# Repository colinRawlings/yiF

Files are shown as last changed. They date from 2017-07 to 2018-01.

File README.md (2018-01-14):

# The yiF
*a foolish combination of action cameras and SLR lenses*

## introduction 

This is a project seeking to replace an action cameras fisheye lens with one of the low cost plastic bodied EFs STM zoom lenses from Canon.  Ideally this combines the action camera's high frame rates (HD at 240 frames/second) with the lens' zoom, depth of field control and active image stabilisation.  Some example footage is here:

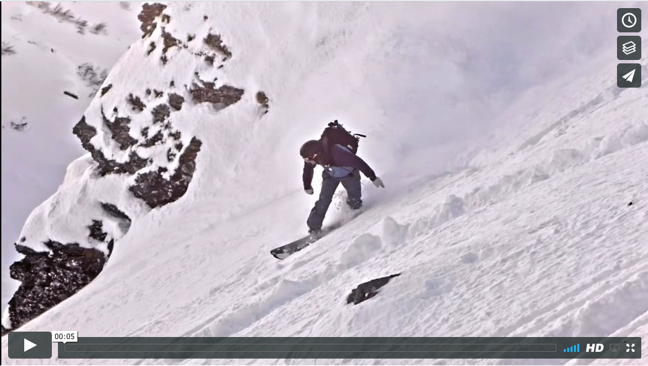
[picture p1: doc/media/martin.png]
example footage (https://vimeo.com/224622844)


The lens is controlled via an Arduino micro and a Yi 4k+ was used for the action camera.  Via the arduino the lens' focus, aperture and image stabilisation motors can be controlled.  The housing is 3D printed and a commlite EF-EOSM adaptor is used for mounting the lens.

For video monitoring the Yi's in-built display combined with an optical viewfinder (the kinotehnik LCDVF 3/2) or an external monitor (smartphone or the ikan VL35) was used.  

The system was tested with several of the EFs STM lenses (10-18 mm, 18-135 mm f3.5 and 55-250 mm f4) and a sigma 35 mm f1.4. The system exhibits a roughly 3x crop sensor, this amplifies the available travel of the image stabiliser, increases the reach of the lens and improves the depth of field control.  

So far nothing bad has happened to the lenses however: 

**You can apparently burn the aperture motor in Canon lenses quite easily.**

*I take no responsibility for any damage caused by the things in this repo.*

The starting point for this work was this article:

https://pickandplace.wordpress.com/2011/10/05/canon-ef-s-protocol-and-electronic-follow-focus/

from here I used a Saleae logic analyser to record the conversations between the lenses and a 650D.  These were then analysed in Matlab since in particular I needed the command to start the image stabilisation motor and activate the manual focus ring (the STM lenses are “focus by wire”).

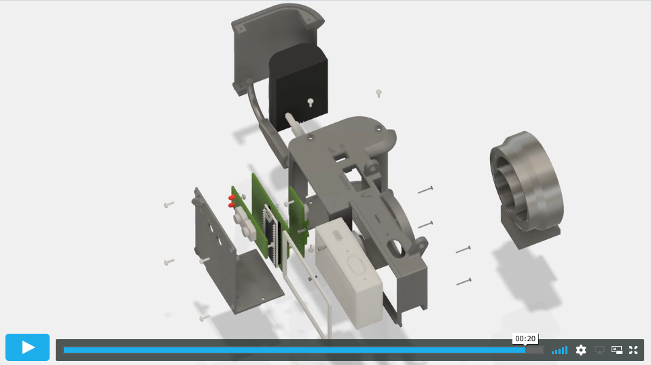
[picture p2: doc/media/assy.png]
assembly (https://vimeo.com/248812464)


## code

This comes in several parts

* A python class for communicating over usb (/serial port) with the arduino.
* [The arduino code](https://github.com/colinRawlings/yiFu)
* The matlab (/octave?) code for parsing the csv files generated by the logic analyser

## cad

The cad was done in Fusion (free for the first year).  The assembly is here: http://a360.co/2sxdWEE

the stl files for printing are in cad/fab.  They are only suitable for selective laser sintering or HP jet fusion of nylon.  I used [3Dhubs.com](https://www.3dhubs.com) to find a nearby printer.

## electronics

The electronics design was done in kicad.  Note the arduino can control the power to the lens.  The entire lens is switch off after each movement of the aperture motor rather than relying on the motor off command being successfully received.  The gerber files are in elec/fab.  I eventually settled on powering the system with an LP-E6 camera battery.

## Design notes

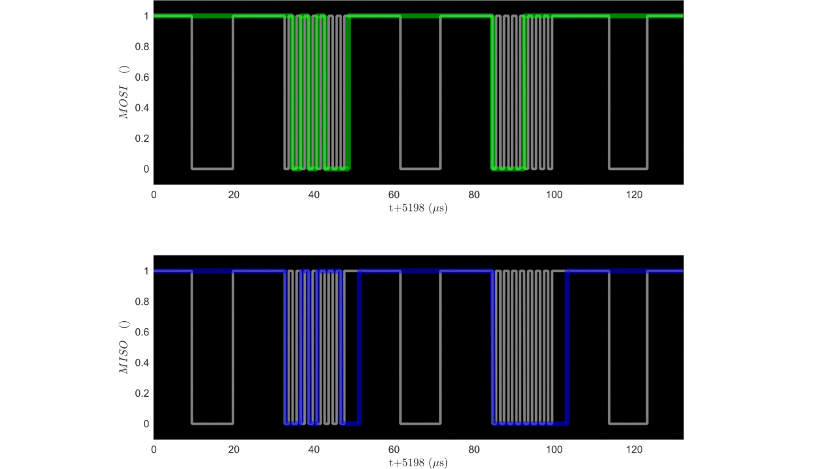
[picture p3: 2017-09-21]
doc/media/anim.gif

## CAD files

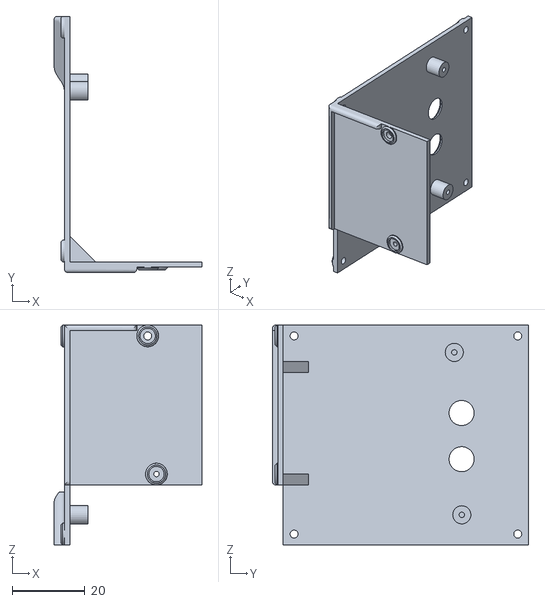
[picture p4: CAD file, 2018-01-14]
cad/fab/case_back.stl
40.6 x 70.5 x 60.5

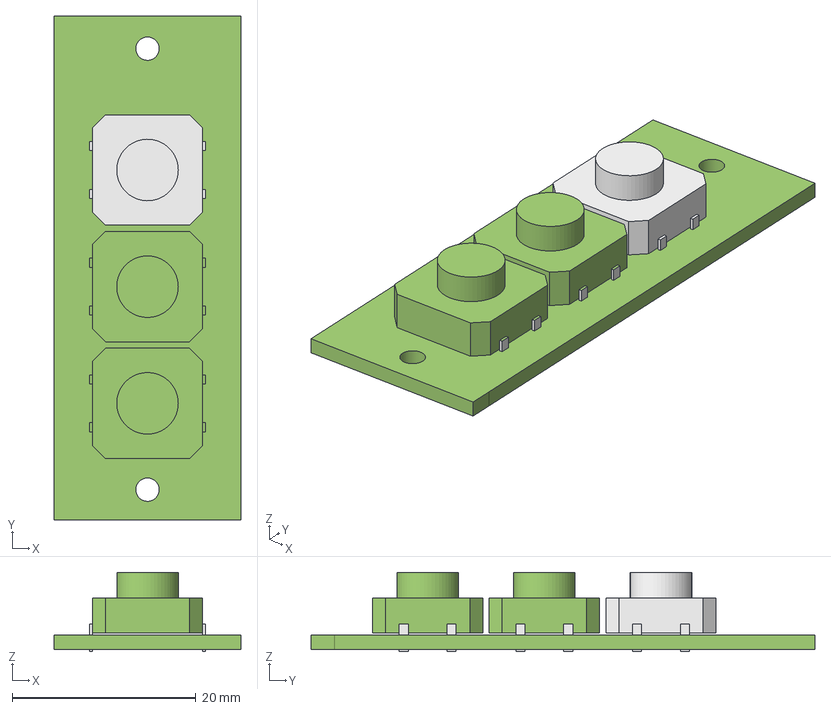
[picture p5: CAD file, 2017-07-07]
pcb/ard_shield/cad/brd2.step
20.3 x 54.9 x 8.60 mm

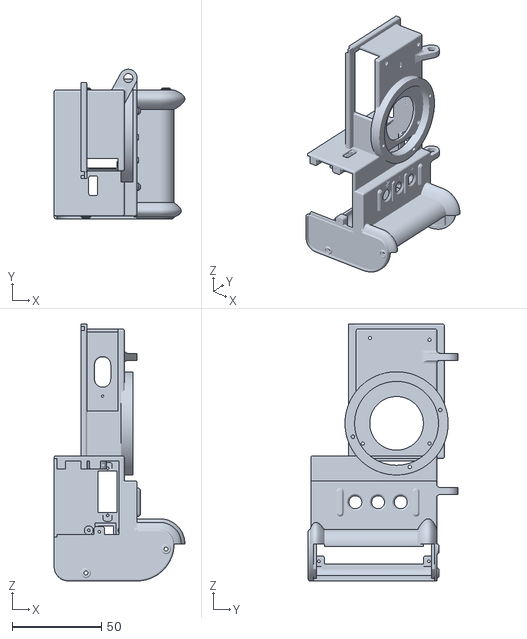
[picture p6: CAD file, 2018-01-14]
cad/fab/housing.stl
73.1 x 83.6 x 143.7

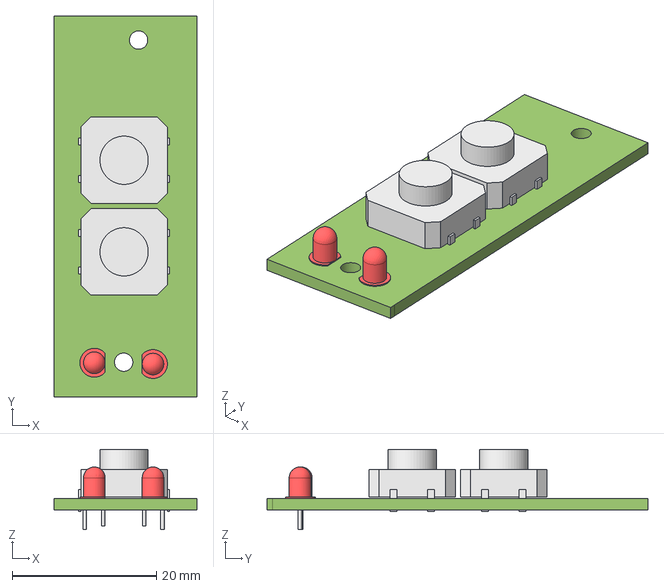
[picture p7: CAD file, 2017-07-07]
pcb/ard_shield/cad/brd3.step
19.8 x 52.8 x 11.1 mm

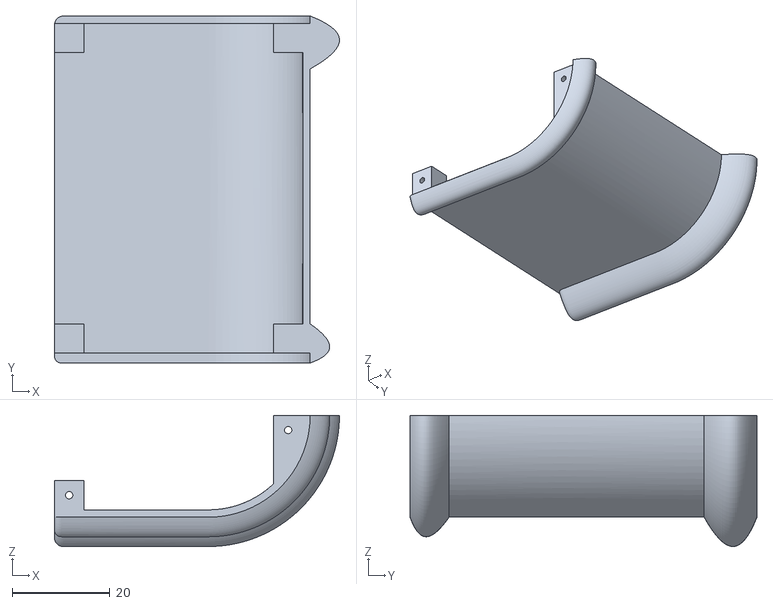
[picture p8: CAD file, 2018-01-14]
cad/fab/battery_hatch.stl
58.3 x 71.0 x 26.8

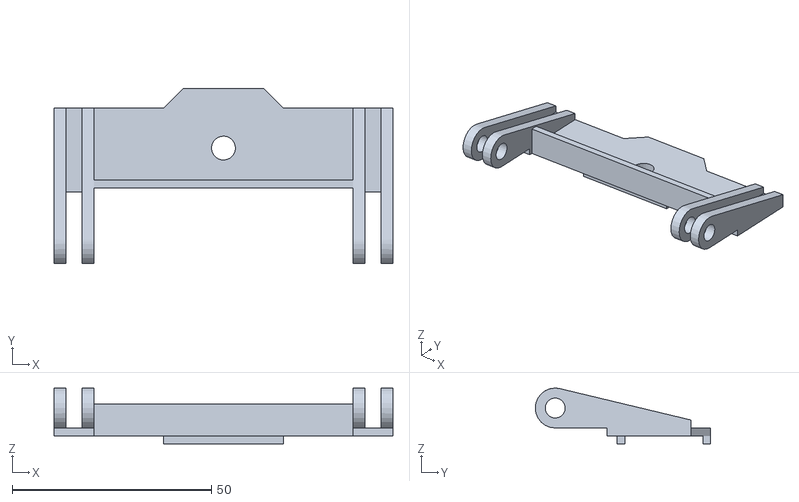
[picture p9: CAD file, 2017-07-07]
cad/fab/screen_mnt.stl
85.0 x 44.0 x 14.0

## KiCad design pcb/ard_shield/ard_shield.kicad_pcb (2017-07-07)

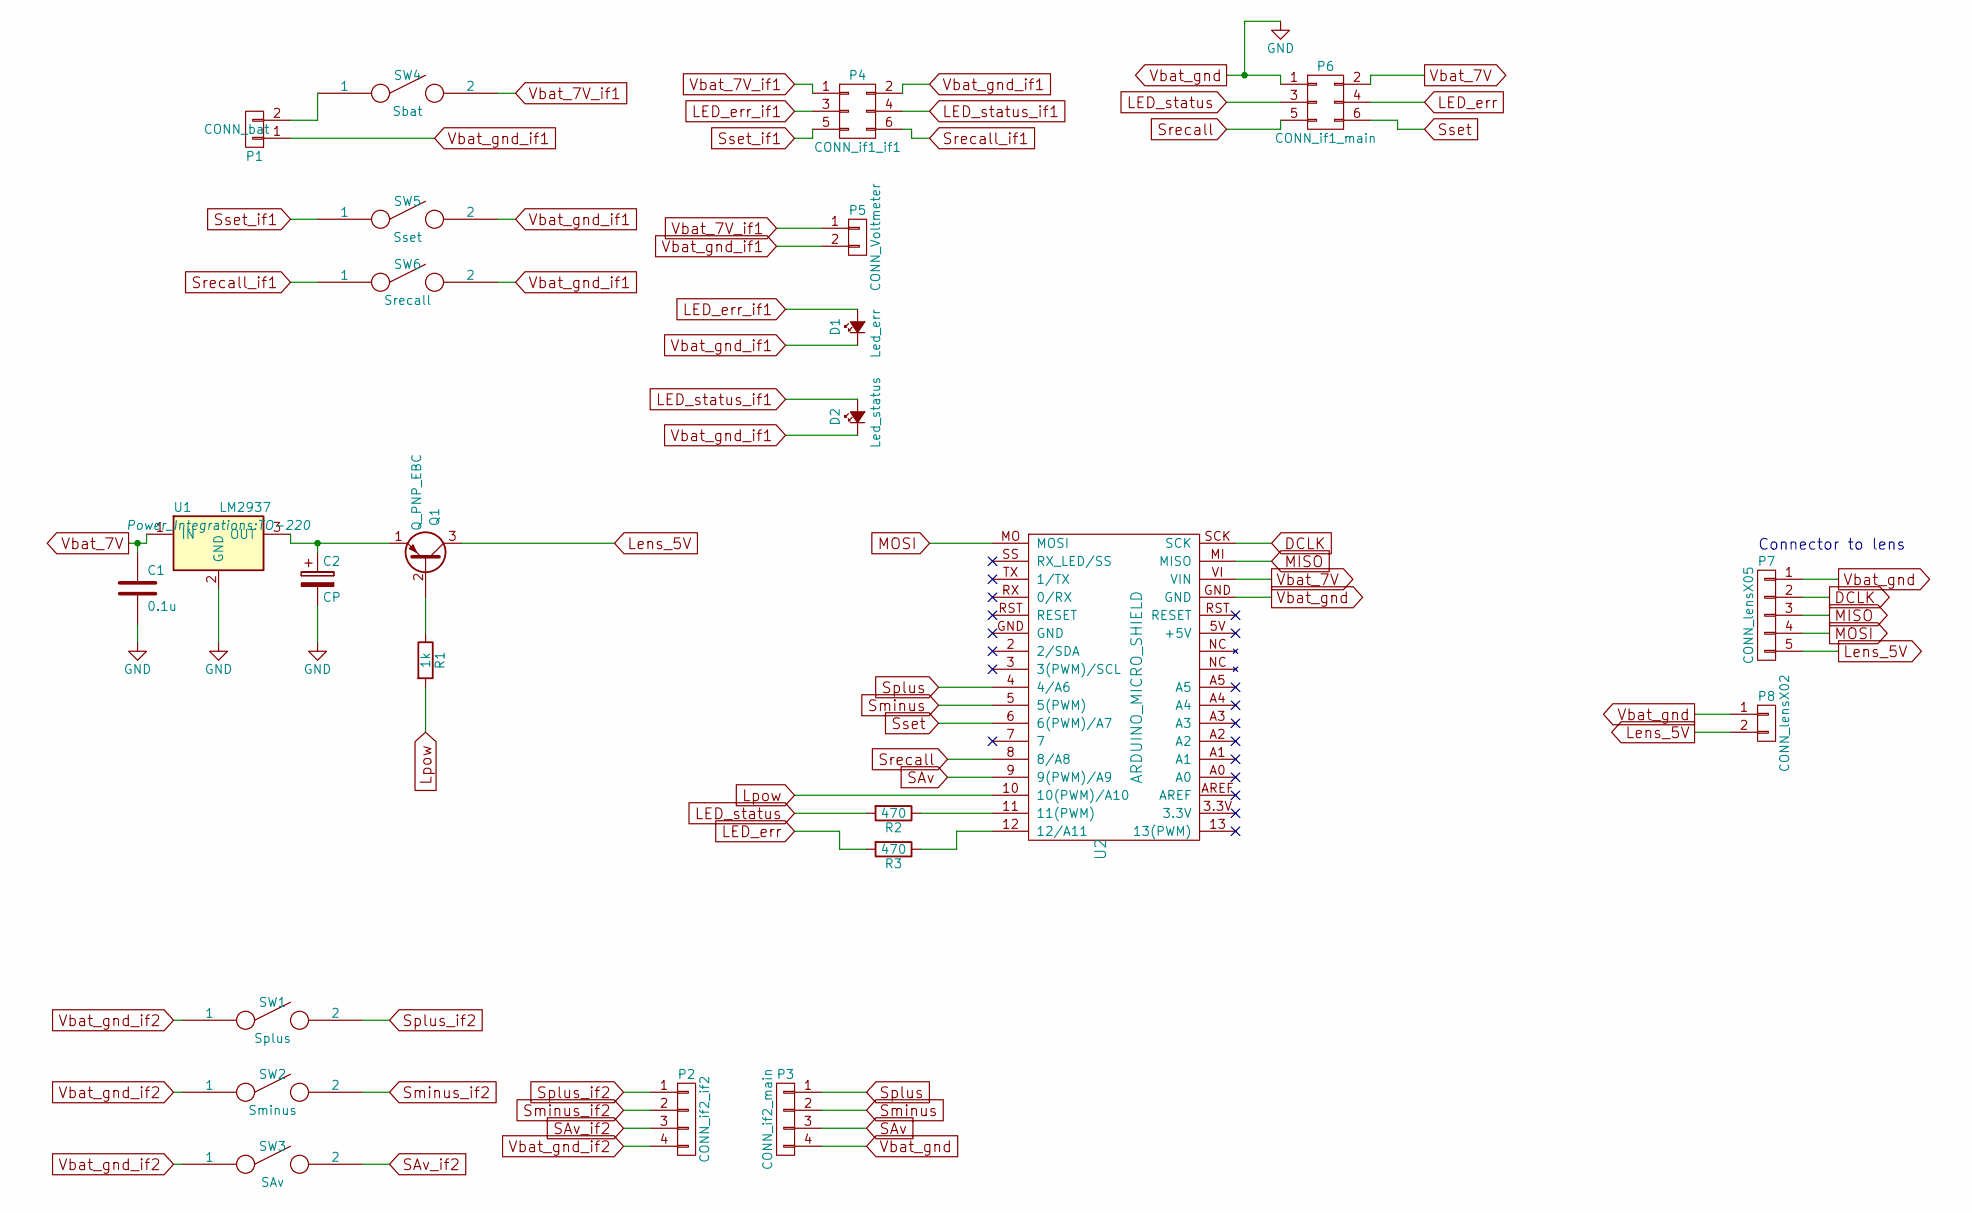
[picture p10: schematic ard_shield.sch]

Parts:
C1: 0.1u; C_Disc_D3_P2.5
C2: CP; C_Rect_L7_W2_P5
D1: Led_err; LED-3MM
D2: Led_status; LED-3MM
P1: CONN_bat; Pin_Header_Angled_1x02
P2: CONN_if2_if2; Pin_Header_Angled_1x04
P3: CONN_if2_main; Socket_Strip_Angled_1x04
P4: CONN_if1_if1; Socket_Strip_Straight_2x03
P5: CONN_Voltmeter; Pin_Header_Straight_1x02
P6: CONN_if1_main; Pin_Header_Straight_2x03
P7: CONN_lensX05; Socket_Strip_Angled_1x05
P8: CONN_lensX02; Socket_Strip_Angled_1x02
Q1: Q_PNP_EBC
R1: 1k; Resistor_Horizontal_RM7mm
R2, R3: 470; Resistor_Horizontal_RM7mm
SW1: Splus; SW_PUSH-12mm
SW2: Sminus; SW_PUSH-12mm
SW3: SAv; SW_PUSH-12mm
SW4: Sbat; SW_Matias_Quiet
SW5: Sset; SW_PUSH-12mm
SW6: Srecall; SW_PUSH-12mm
U1: LM2937; TO-220
U2: ARDUINO_MICRO_SHIELD

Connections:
DCLK: P7.2, U2.SCK
LED_err: P6.4, R3.2
LED_err_if1: D1.2 (A), P4.3
LED_status: P6.3, R2.2
LED_status_if1: D2.2 (A), P4.4
Lens_5V: P7.5, P8.2, Q1.3 (C)
Lpow: R1.2, U2.10 (10(PWM)/A10)
MISO: P7.3, U2.MI (MISO)
MOSI: P7.4, U2.MO (MOSI)
unnamed: C2.1, Q1.1 (E), U1.3 (OUT)
unnamed: P1.2, SW4.1
unnamed: Q1.2 (B), R1.1
unnamed: R2.1, U2.11 (11(PWM))
unnamed: R3.1, U2.12 (12/A11)
SAv: P3.3, U2.9 (9(PWM)/A9)
SAv_if2: P2.3, SW3.2
Sminus: P3.2, U2.5 (5(PWM))
Sminus_if2: P2.2, SW2.2
Splus: P3.1, U2.4 (4/A6)
Splus_if2: P2.1, SW1.2
Srecall: P6.5, U2.8 (8/A8)
Srecall_if1: P4.6, SW6.1
Sset: P6.6, U2.6 (6(PWM)/A7)
Sset_if1: P4.5, SW5.1
Vbat_7V: C1.1, P6.2, U1.1 (IN), U2.VI (VIN)
Vbat_7V_if1: P4.1, P5.1, SW4.2
Vbat_gnd: C1.2, C2.2, P3.4, P6.1, P7.1, P8.1, U1.2 (GND), U2.GND
Vbat_gnd_if1: D1.1 (K), D2.1 (K), P1.1, P4.2, P5.2, SW5.2, SW6.2
Vbat_gnd_if2: P2.4, SW1.1, SW2.1, SW3.1

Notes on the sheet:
Connector to lens

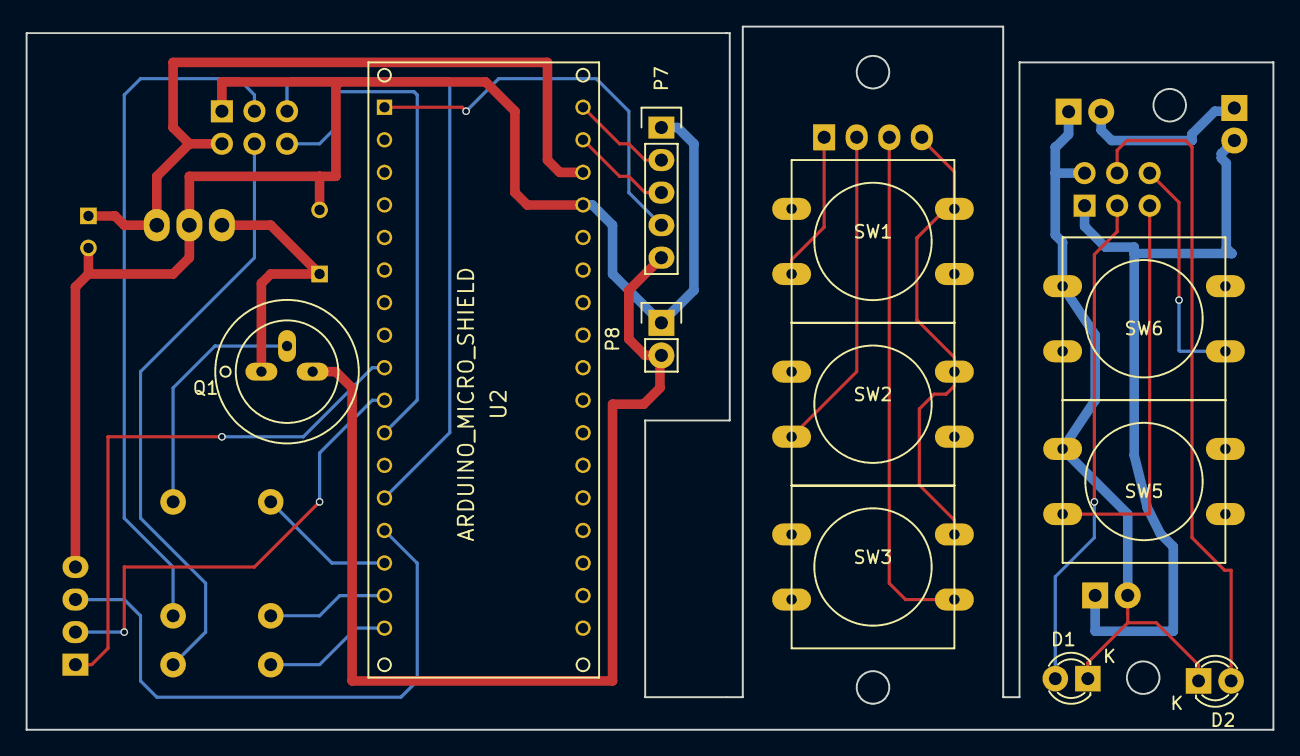
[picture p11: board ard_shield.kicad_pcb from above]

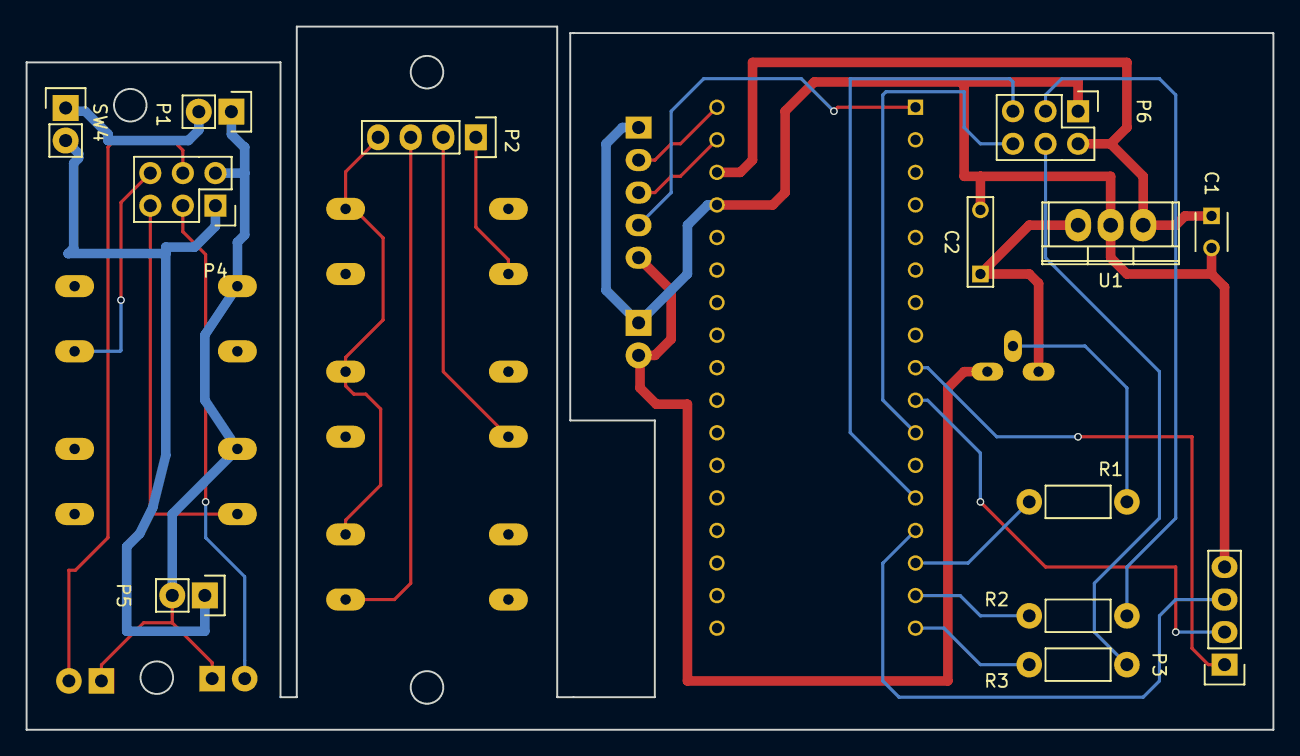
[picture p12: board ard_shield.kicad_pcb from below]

Board: 2 copper layers, 97.3 x 54.9 mm, 24 parts (13 on the bottom side), 29 nets.

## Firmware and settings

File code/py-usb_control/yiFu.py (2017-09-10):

class yiFu(object):
    def __init__(self, addr=None, verbose_mode=False):
        import serial

        # --- attributes
        self.verbose = verbose_mode
        self.addr = addr
        self.lens_desc = ''
        self.move_timeout_ms = 1000

        # --- r properties
        self._status = None  # a dict interpreting the various status bits
        self._FL = None
        self._FD = None
        self._min_FL = None
        self._max_FL = None

        # --- start the lens
        self.connect()
        self.init_lens()

    @property
    def status(self):
        """
        status register of the lens
        :return: dict of detailing the state of the lens' status register
        """

        # --- get 0 padded string representation of status register
        response = self.send_lens_cmd(['90', 'B9', '00'], fast_mode=True)
        state_str = bin(int('0x' + response['MISO'][2], 16))
        state_str = state_str[2:]
        for p in range(8 - len(state_str)):
            state_str = '0' + state_str

        self._status = dict(AF_switch=bool(int(state_str[0])),
                            F_move=bool(int(state_str[5])),
                            F_acc=bool(int(state_str[2])),
                            FD_endStop=bool(int(state_str[3])),
                            status_byte=state_str)

        return self._status

    @property
    def min_FL(self):
        """

        :return: the lens' minimium focal length in mm as an integer
        """

        return self._min_FL

    @property
    def max_FL(self):
        """

        :return: the lens' maximium focal length in mm as an integer
        """

        return self._max_FL

    @property
    def FL(self):
        """

        :return: the current focal length of the lens in mm as an integer
        """

        response = self.send_lens_cmd(['A0', '00', '00'], fast_mode=True)
        FL_hex = '0x' + response['MISO'][1] + response['MISO'][2]
        self._FL = int(FL_hex, 16)
        return self._FL

    @FL.setter
    def FL(self, value):

        print('FL can only be set manually')

    @property
    def FD(self):
        """

        :return: the current focal distance in lens encoder tics as an integer
        """

        response = self.send_lens_cmd(['C0', '00', '00'], fast_mode=True)

        FD_hex = '0x' + response['MISO'][1] + response['MISO'][2]
        self._FD = int(FD_hex, 16)
        return self._FD

    @FD.setter
    def FD(self, target_FD):
        step = target_FD - self.FD
        MSB, LSB = self.signed_decimal_to_two_bytes(step)

        response = self.send_lens_cmd(['44', MSB, LSB, '00', '00', '00'], fast_mode=True)

        self.wait_focus_move()

    def wait_focus_move(self):
        """

        method which blocks execution until the lens completes its move

        :return:
        """

        import time

        T0 = time.time()

        finished = False
        aborted = False

        while not finished:
            T1 = time.time()
            the_status = self.status

            if not the_status['F_move'] or the_status['FD_endStop']:
                finished = True

            if 1e3 * (T1 - T0) > self.move_timeout_ms:
                finished = True
                aborted = True

        if aborted:
            print('wait_focus_move timed out')
        elif self.verbose:
            print('move complete in {}s'.format(T1 - T0))

    @staticmethod
    def signed_decimal_to_two_bytes(value):
        """
        convert to lens format

        :param value: signed integer
        :return: most significant byte, least significant byte as hex without leading '0x'
        """

        hex_str = hex(value & 0xffff)
        hex_str = hex_str[2:]
        for p in range(4 - len(hex_str)):
            hex_str = '0' + hex_str

        return hex_str[0:2], hex_str[2:4]

    def get_EFu_addr(self):
        """

        assumes that the yiFu is the device attached to /dev/tty.usbmodem####

        function for opening the serial port

        :return: a string containing the path to the serial port
        """

        import subprocess as sp

        output = sp.check_output(['ls', r'/dev/'])
        devList = self.div_str_into_lines(output)

        # - get the ttyUSBmodem device
        arduino_found = False
        for dev in devList:
            if 'tty.usbmodem' in dev:
                arduino_found = True
                ard_addr = dev

        if not arduino_found:
            raise RuntimeError('No arduino found')

        return '/dev/' + ard_addr

    @staticmethod
    def div_str_into_lines(the_str):
        """
        break up a literal string into a list of lines.  Helper function.

        :param the_str: an input string containing r'\n' characters
        :return: a list containing a string with the lines (all newlines chars are removed)
        """

        lines = []
        curr_line = ''
        n_char = 0

        while n_char < len(the_str):
            if the_str[n_char] != '\n':
                curr_line = curr_line + the_str[n_char]
            else:
                lines.append(curr_line)
                curr_line = ''
            n_char += 1

        return lines

    def serial_wr(self, cmd_str, endComm='----------------END\r\n', r_timeout=5):
        """

        :param cmd_str: Comma separated list of hex codes to pass to the lens.  First character should be a + to switch
         to fast mode or a - to switch to slow mode.
        :param endComm: The last line of the response that the arduino will send
        :param r_timeout: how to wait for the endComm line before giving up

        :return: A list of strings corresponding to the formatted response from the lens.
        """

        import time

        self.ser.flushInput()

        if not self.ser.isOpen():
            raise RuntimeError('Serial port is closed')

        # --- perform write then read response
        self.ser.write(cmd_str)

        finished = False
        lines = []
        start_time = time.time()
        while not finished:

            line = self.ser.readline()

            if self.verbose:
                line_disp = line.replace('\r', '')
                line_disp = line_disp.replace('\n', '')
                print(line_disp)

            lines.append(line)
            if line == endComm:
                finished = True

            if time.time() - start_time > r_timeout:
                finished = True

        return lines

    def send_lens_cmd(self, cmd_list, fast_mode):
        """


        :param cmd_list: list of hex bytes (as strings) to pass to the lens.  e.g. ['00','0A','FF','00']
        :param fast_mode: Whether the clock speed used when transmitting to the lensshould be fast (500kHz) or slow
         (100kHz).
        :return: a dictionary summarising the result of sending the command to the lens
        """

        # --- build command string
        if fast_mode:
            cmd_str = '+'
        else:
            cmd_str = '-'
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

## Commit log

2017-07-07 Initial commit: cad and elec files
    also python files
    [ard_shield-B.Cu.gbr, ard_shield-B.Mask.gbr, ard_shield-B.Paste.gbr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]
2017-08-02 add submodule for arduino oop code
2017-09-10 - improved error checking in py code - add current state of arduino code
    [yiFu.py]
2018-01-14 changes for new casing
    [battery_hatch.stl, case_back.stl, housing.stl]
